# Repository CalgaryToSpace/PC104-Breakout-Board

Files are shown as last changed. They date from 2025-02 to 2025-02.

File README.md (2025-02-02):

# PC104-Breakout-Board
A quick PCB to break out the PC104 connector for flatsat testing

## PCB

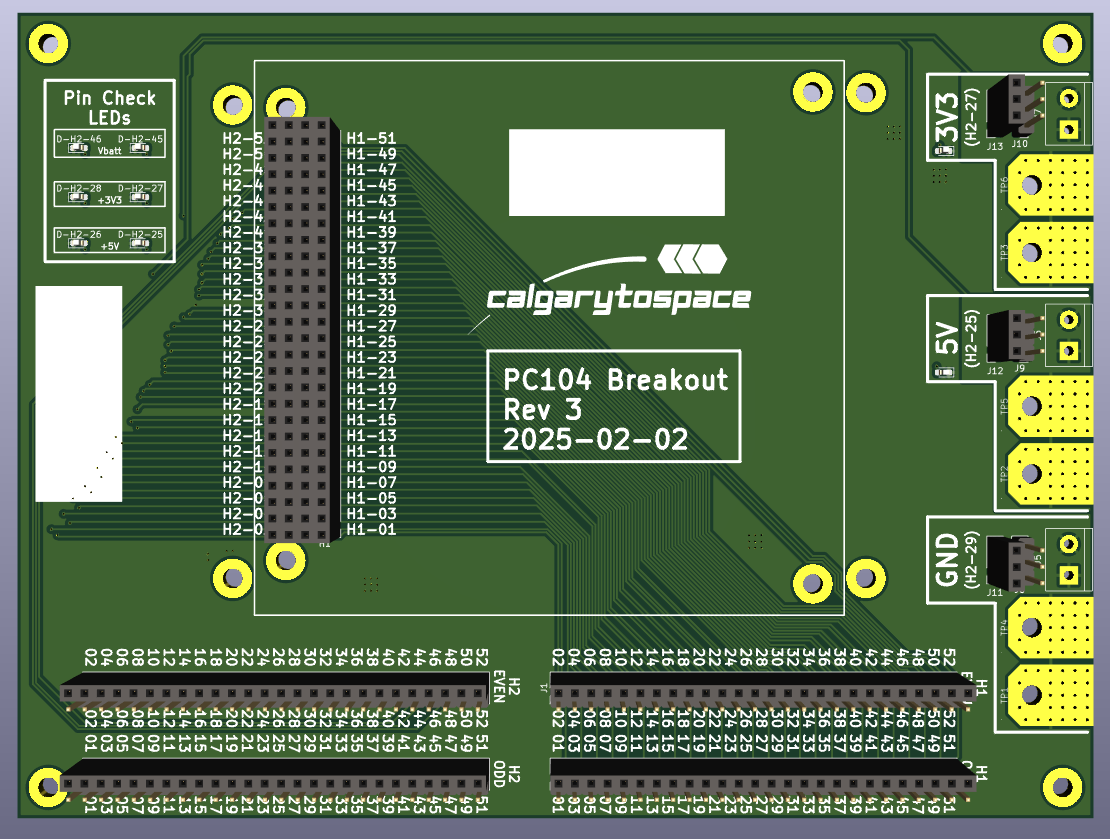
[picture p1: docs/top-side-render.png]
Top Side Render

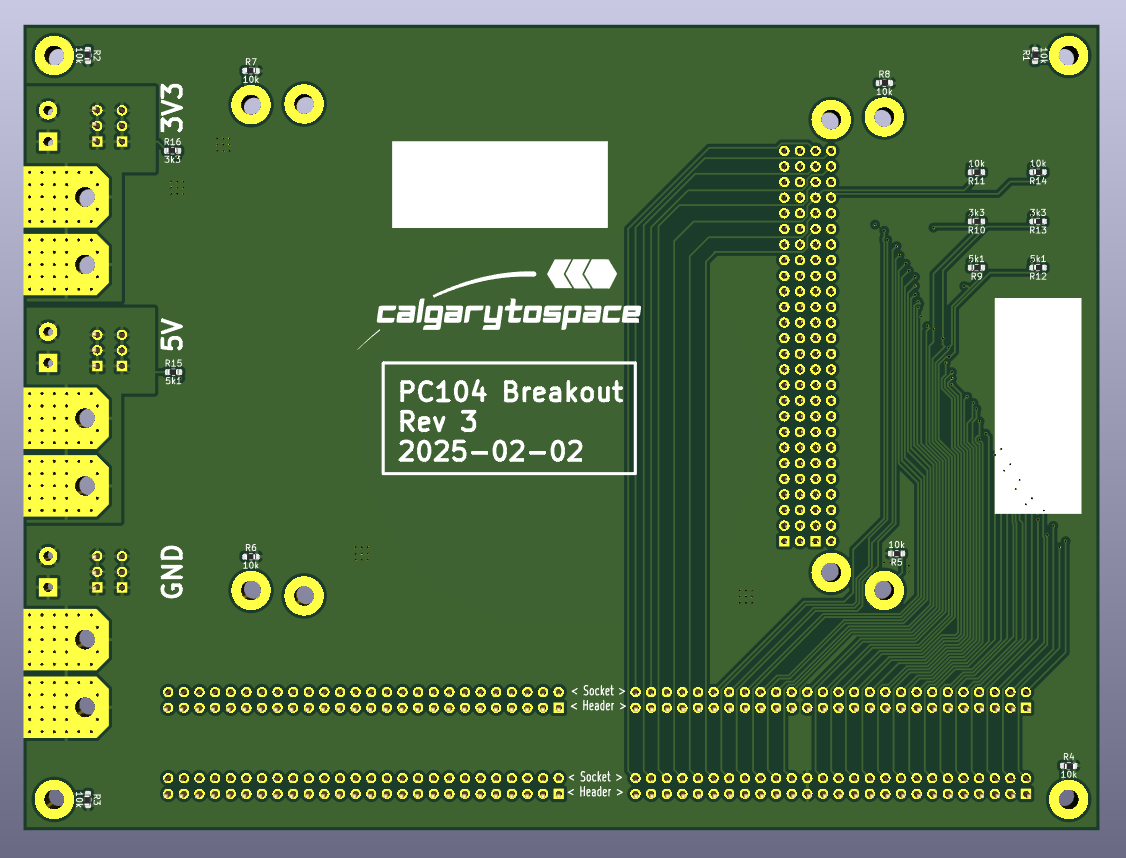
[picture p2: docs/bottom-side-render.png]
Bottom Side Render


## Resources

* PC104 Dimensional Specification: https://dspace.cvut.cz/bitstream/handle/10467/94475/F3-BP-2021-Geib-Filip-bp_GEIB.pdf
    * Figure 2.2 (Page 11): Technical dimensional drawing
    * Appendix C (Page 65): PC104 Connector Pinout
        * Note: This is somewhat of a recommendation; every mission selects their own pinout.

## License

CERN Open Hardware Licence Version 2 - Permissive

Feel free to use as you see fit!

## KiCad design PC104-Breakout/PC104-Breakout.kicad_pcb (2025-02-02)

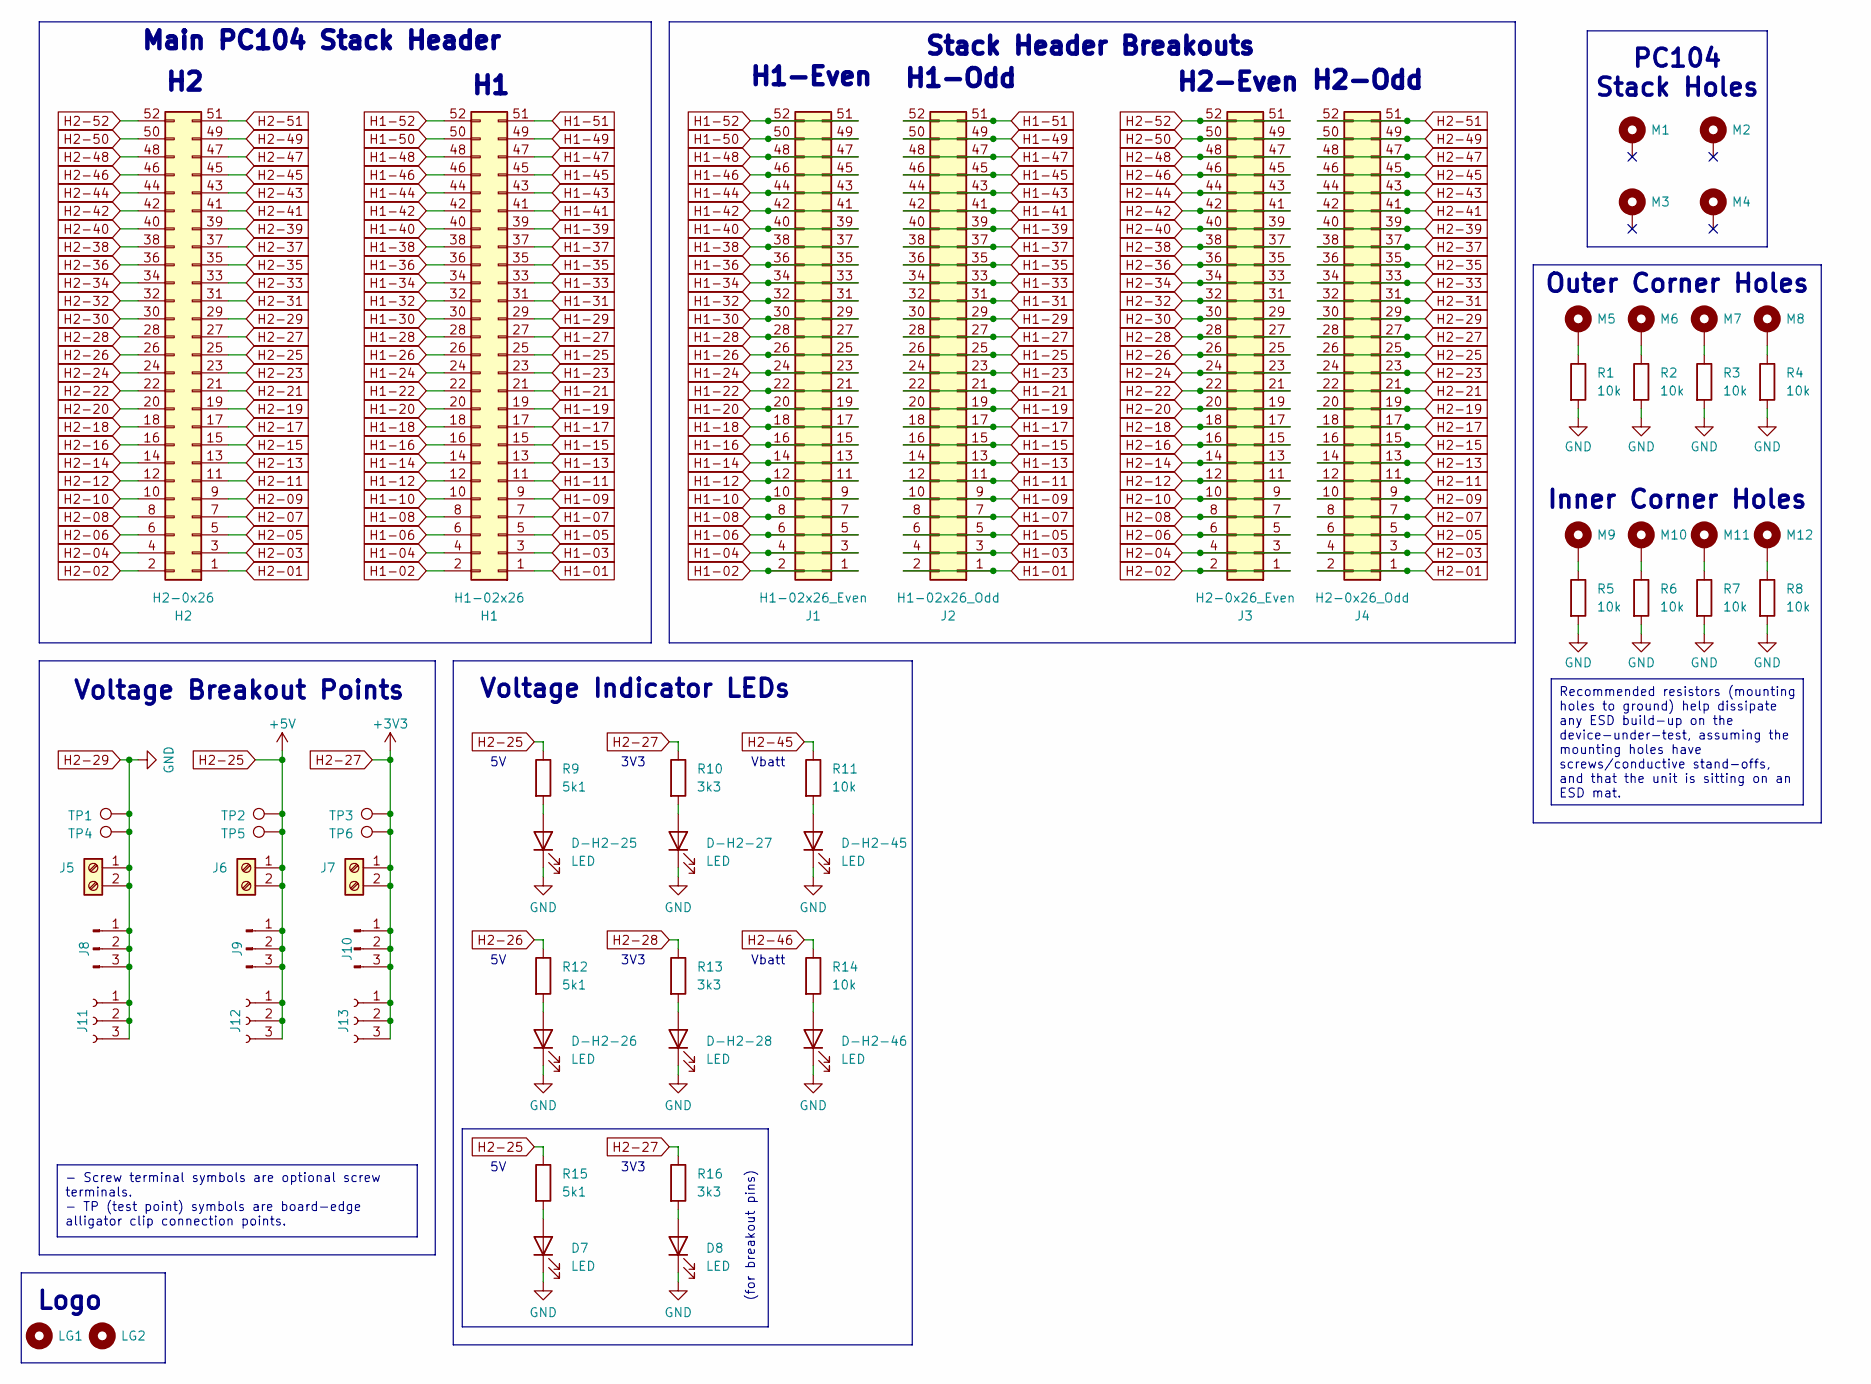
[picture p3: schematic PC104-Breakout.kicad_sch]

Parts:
D7, D8: LED; LED_0603_1608Metric_Pad1.05x0.95mm_HandSolder
D-H2-25, D-H2-26, D-H2-27, D-H2-28, D-H2-45, D-H2-46: LED; LED_0603_1608Metric_Pad1.05x0.95mm_HandSolder
H1: H1-02x26; PinSocket_2x26_P2.54mm_Vertical_TightPlacement
H2: H2-0x26; PinSocket_2x26_P2.54mm_Vertical_TightPlacement
J1: H1-02x26_Even; PinHeader_2x26_P2.54mm_Vertical_HeaderAndSocket
J2: H1-02x26_Odd; PinHeader_2x26_P2.54mm_Vertical_HeaderAndSocket
J3: H2-0x26_Even; PinHeader_2x26_P2.54mm_Vertical_HeaderAndSocket
J4: H2-0x26_Odd; PinHeader_2x26_P2.54mm_Vertical_HeaderAndSocket
J5, J6, J7: Screw_Terminal_01x02; TerminalBlock_bornier-2_P5.08mm
J8, J9, J10: Conn_01x02; PinHeader_1x03_P2.54mm_Vertical
J11, J12, J13: Conn_01x03_Socket; PinSocket_1x03_P2.54mm_Vertical
LG1, LG2: MountingHole; CTS-Logo-50x25
M1, M2, M3, M4, M5, M6, M7, M8, M9, M10, M11, M12: MountingHole_Pad; MountingHole_3.2mm_M3_Pad
R1, R2, R3, R4, R5, R6, R7, R8, R11, R14: 10k; R_0603_1608Metric_Pad0.98x0.95mm_HandSolder
R9, R12, R15: 5k1; R_0603_1608Metric_Pad0.98x0.95mm_HandSolder
R10, R13, R16: 3k3; R_0603_1608Metric_Pad0.98x0.95mm_HandSolder
TP1, TP2, TP3, TP4, TP5, TP6: TestPoint; EdgeAlligatorConnector

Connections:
H1-01: H1.1, J2.1, J2.2
H1-02: H1.2, J1.1, J1.2
H1-03: H1.3, J2.3, J2.4
H1-04: H1.4, J1.3, J1.4
H1-05: H1.5, J2.5, J2.6
H1-06: H1.6, J1.5, J1.6
H1-07: H1.7, J2.7, J2.8
H1-08: H1.8, J1.7, J1.8
H1-09: H1.9, J2.9, J2.10
H1-10: H1.10, J1.9, J1.10
H1-11: H1.11, J2.11, J2.12
H1-12: H1.12, J1.11, J1.12
H1-13: H1.13, J2.13, J2.14
H1-14: H1.14, J1.13, J1.14
H1-15: H1.15, J2.15, J2.16
H1-16: H1.16, J1.15, J1.16
H1-17: H1.17, J2.17, J2.18
H1-18: H1.18, J1.17, J1.18
H1-19: H1.19, J2.19, J2.20
H1-20: H1.20, J1.19, J1.20
H1-21: H1.21, J2.21, J2.22
H1-22: H1.22, J1.21, J1.22
H1-23: H1.23, J2.23, J2.24
H1-24: H1.24, J1.23, J1.24
H1-25: H1.25, J2.25, J2.26
H1-26: H1.26, J1.25, J1.26
H1-27: H1.27, J2.27, J2.28
H1-28: H1.28, J1.27, J1.28
H1-29: H1.29, J2.29, J2.30
H1-30: H1.30, J1.29, J1.30
H1-31: H1.31, J2.31, J2.32
H1-32: H1.32, J1.31, J1.32
H1-33: H1.33, J2.33, J2.34
H1-34: H1.34, J1.33, J1.34
H1-35: H1.35, J2.35, J2.36
H1-36: H1.36, J1.35, J1.36
H1-37: H1.37, J2.37, J2.38
H1-38: H1.38, J1.37, J1.38
H1-39: H1.39, J2.39, J2.40
H1-40: H1.40, J1.39, J1.40
H1-41: H1.41, J2.41, J2.42
H1-42: H1.42, J1.41, J1.42
H1-43: H1.43, J2.43, J2.44
H1-44: H1.44, J1.43, J1.44
H1-45: H1.45, J2.45, J2.46
H1-46: H1.46, J1.45, J1.46
H1-47: H1.47, J2.47, J2.48
H1-48: H1.48, J1.47, J1.48
H1-49: H1.49, J2.49, J2.50
H1-50: H1.50, J1.49, J1.50
H1-51: H1.51, J2.51, J2.52
H1-52: H1.52, J1.51, J1.52
H2-01: H2.1, J4.1, J4.2
H2-02: H2.2, J3.1, J3.2
H2-03: H2.3, J4.3, J4.4
H2-04: H2.4, J3.3, J3.4
H2-05: H2.5, J4.5, J4.6
H2-06: H2.6, J3.5, J3.6
H2-07: H2.7, J4.7, J4.8
H2-08: H2.8, J3.7, J3.8
H2-09: H2.9, J4.9, J4.10
H2-10: H2.10, J3.9, J3.10
H2-11: H2.11, J4.11, J4.12
H2-12: H2.12, J3.11, J3.12
H2-13: H2.13, J4.13, J4.14
H2-14: H2.14, J3.13, J3.14
H2-15: H2.15, J4.15, J4.16
H2-16: H2.16, J3.15, J3.16
H2-17: H2.17, J4.17, J4.18
H2-18: H2.18, J3.17, J3.18
H2-19: H2.19, J4.19, J4.20
H2-20: H2.20, J3.19, J3.20
H2-21: H2.21, J4.21, J4.22
H2-22: H2.22, J3.21, J3.22
H2-23: H2.23, J4.23, J4.24
H2-24: H2.24, J3.23, J3.24
H2-25: H2.25, J4.25, J4.26, J6.1, J6.2, J9.1, J9.2, J9.3, J12.1, J12.2, J12.3, R9.1, R15.1, TP2.1, TP5.1
H2-26: H2.26, J3.25, J3.26, R12.1
H2-27: H2.27, J4.27, J4.28, J7.1, J7.2, J10.1, J10.2, J10.3, J13.1, J13.2, J13.3, R10.1, R16.1, TP3.1, TP6.1
H2-28: H2.28, J3.27, J3.28, R13.1
H2-29: D7.1 (K), D8.1 (K), D-H2-25.1 (K), D-H2-26.1 (K), D-H2-27.1 (K), D-H2-28.1 (K), D-H2-45.1 (K), D-H2-46.1 (K), H2.29, J4.29, J4.30, J5.1, J5.2, J8.1, J8.2, J8.3, J11.1, J11.2, J11.3, R1.2, R2.2, R3.2, R4.2, R5.2, R6.2, R7.2, R8.2, TP1.1, TP4.1
H2-30: H2.30, J3.29, J3.30
H2-31: H2.31, J4.31, J4.32
H2-32: H2.32, J3.31, J3.32
H2-33: H2.33, J4.33, J4.34
H2-34: H2.34, J3.33, J3.34
H2-35: H2.35, J4.35, J4.36
H2-36: H2.36, J3.35, J3.36
H2-37: H2.37, J4.37, J4.38
H2-38: H2.38, J3.37, J3.38
H2-39: H2.39, J4.39, J4.40
H2-40: H2.40, J3.39, J3.40
H2-41: H2.41, J4.41, J4.42
H2-42: H2.42, J3.41, J3.42
H2-43: H2.43, J4.43, J4.44
H2-44: H2.44, J3.43, J3.44
H2-45: H2.45, J4.45, J4.46, R11.1
H2-46: H2.46, J3.45, J3.46, R14.1
H2-47: H2.47, J4.47, J4.48
H2-48: H2.48, J3.47, J3.48
H2-49: H2.49, J4.49, J4.50
H2-50: H2.50, J3.49, J3.50
H2-51: H2.51, J4.51, J4.52
H2-52: H2.52, J3.51, J3.52
unnamed: D7.2 (A), R15.2
unnamed: D8.2 (A), R16.2
unnamed: D-H2-25.2 (A), R9.2
unnamed: D-H2-26.2 (A), R12.2
unnamed: D-H2-27.2 (A), R10.2
unnamed: D-H2-28.2 (A), R13.2
unnamed: D-H2-45.2 (A), R11.2
unnamed: D-H2-46.2 (A), R14.2
unnamed: M5.1, R1.1
unnamed: M6.1, R2.1
unnamed: M7.1, R3.1
unnamed: M8.1, R4.1
unnamed: M9.1, R5.1
unnamed: M10.1, R6.1
unnamed: M11.1, R7.1
unnamed: M12.1, R8.1

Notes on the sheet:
- Screw terminal symbols are optional screw terminals. - TP (test point) symbols are board-edge alligator clip connection points.
Recommended resistors (mounting holes to ground) help dissipate any ESD build-up on the device-under-test, assuming the mounting holes have screws/conductive stand-offs, and that the unit is sitting on an ESD mat.
(for breakout pins)
Outer Corner Holes
Vbatt
H2-Odd
Voltage Indicator LEDs
Inner Corner Holes
PC104 Stack Holes
Stack Header Breakouts
Logo
3V3
Voltage Breakout Points
Main PC104 Stack Header
H1-Odd
H1-Even
H2-Even

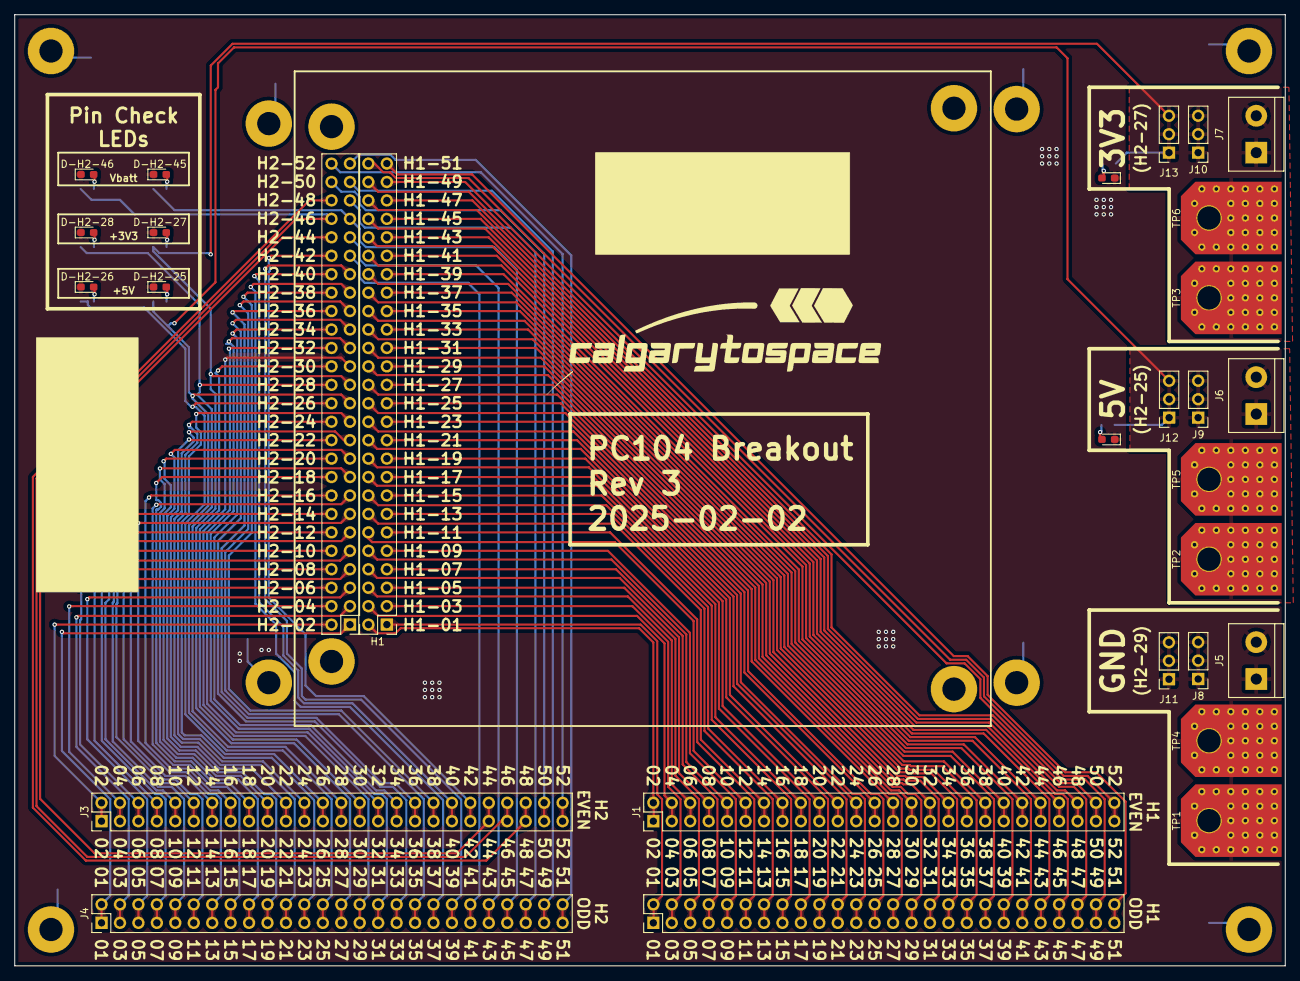
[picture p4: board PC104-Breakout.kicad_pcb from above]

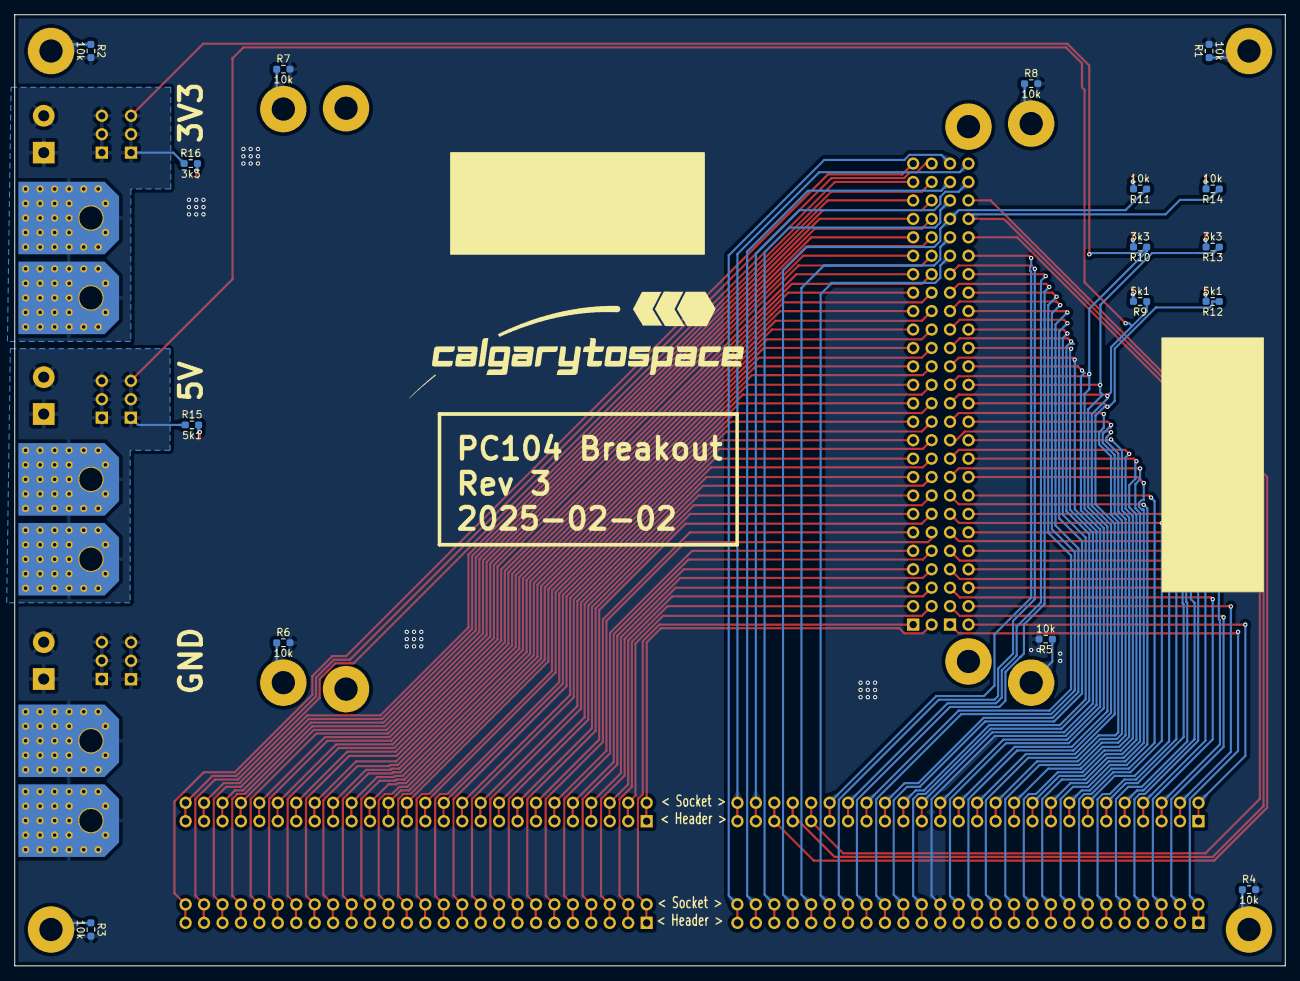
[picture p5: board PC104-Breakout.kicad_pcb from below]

Board: 2 copper layers, 175.0 x 131.0 mm, 59 parts (17 on the bottom side), 120 nets.

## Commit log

2024-04-27 created schematic
    - H1 and H2
    - GND, 5V, 3V3 connectors
    [PC104-Breakout.kicad_pcb, PC104-Breakout.kicad_sch]
2024-04-27 flipped headers to face correct direction
    [PC104-Breakout.kicad_sch]
2024-04-27 updated pcb file
    updated from schematic
    [PC104-Breakout.kicad_pcb]
2024-05-11 added screwholes
    [PC104-Breakout.kicad_pcb, PC104-Breakout.kicad_sch]
2024-05-14 added silk screens for header pins
    [PC104-Breakout.kicad_pcb]
2024-05-18 Positioned external mounting holes
    [PC104-Breakout.kicad_pcb, PC104-Breakout.kicad_sch]
2024-05-18 Intense layout/positioning of the PC104 spec
    [PC104-Breakout.kicad_pcb]
2024-05-18 Added 3.3V and GND LEDs
    [PC104-Breakout.kicad_pcb, PC104-Breakout.kicad_sch]
2024-05-18 semi final routing
    - routed everything including power pins
    - created GND, 3V3, and 5V pours
    - added vias for diodes / routing
    TODO: fix last two unrouted nets
    [PC104-Breakout.kicad_pcb]
2024-05-18 finished routing
    - fixed final unrouted nets and vias
    - silk screen edits
    [PC104-Breakout.kicad_pcb]
2024-05-18 Fixed LED orientations and finalized board design
    [PC104-Breakout.kicad_pcb, PC104-Breakout.kicad_sch]
2024-05-21 Added silkscreen - created production files
    [PC104-Breakout.kicad_pcb]
2024-05-22 Reorganized PCB layout
    Modified layout files to change board from 4 layers to 2 in order to decrease production costs by $45. Shifted two stack headers to the right of the space allocated for the EPS and rerouted with 2 la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
    [PC104-Breakout.kicad_pcb]
2024-05-22 Completed layout, updated silkscreen and added aesthetic fixes
    [PC104-Breakout.kicad_pcb]
2024-05-22 Created production files
    [PC104-Breakout.kicad_pcb]
2025-02-02 Update for Rev 3, do layout
    [PC104-Breakout.kicad_pcb, PC104-Breakout.kicad_sch]
2025-02-02 Polish 3d models, silkscreen
    [PC104-Breakout.kicad_pcb, PC104-Breakout.kicad_sch]
2025-02-02 Polish silkscreen more
    [PC104-Breakout.kicad_pcb]
2025-02-02 Route H1 breakout
    [PC104-Breakout.kicad_pcb]
2025-02-02 Reroute H1 with breakout flipped
    [PC104-Breakout.kicad_pcb]
2025-02-02 Route both H1 and H2
    [PC104-Breakout.kicad_pcb]
2025-02-02 Finish Rev 3
    [PC104-Breakout.kicad_pcb]
2025-02-02 Fix DRC issues - Rev 3 final
    [PC104-Breakout.kicad_pcb]
